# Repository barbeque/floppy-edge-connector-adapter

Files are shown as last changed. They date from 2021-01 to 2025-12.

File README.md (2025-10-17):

# Floppy Adapter v3
This adapter is intended to allow older computers equipped with 5.25" floppy drives using an edge connector to use a 3.5" floppy drive.

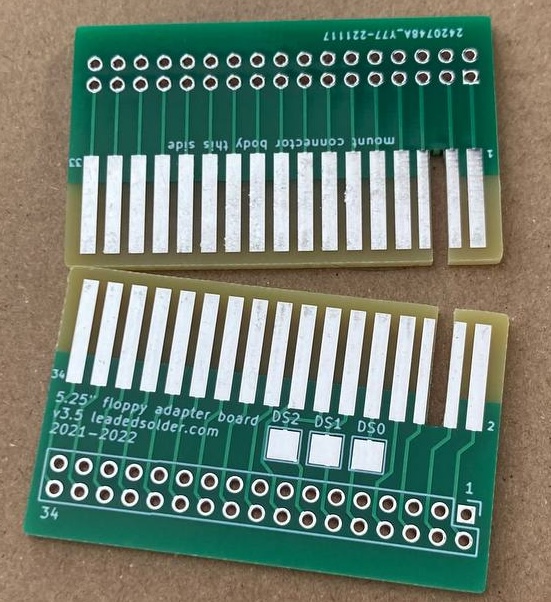
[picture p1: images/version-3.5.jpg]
The floppy adapter board (v3.5), with HASL coating and no bevel.


For long-term reliability, especially in humid environments or when the adapter is expected to be plugged and unplugged often, it's recommended that you pay extra at fabrication time to get hard gold fingers and a bevel. You can bevel it yourself with sandpaper, if needed.

This project was developed as part of a [leaded solder](https://www.leadedsolder.com/) repair of a Sharp X1turbo, and based on an older board developed for a conversion of a NEC PC-8801mkII.

# Version History
## v3.6 (2025)
Move the silkscreen for the female floppy-drive connector to match the label on the bottom of the board. The label was being ignored by assembly houses and this should help correct this behaviour.

## v3.5 (2022)
Add "drive select" breakout pins on the top. This was done to enable a single HxC to emulate two drives on the NEC PC-8801. Thanks to Frio for requesting and co-operating with the development of this version of the adapter.

## v3.0 (2021)
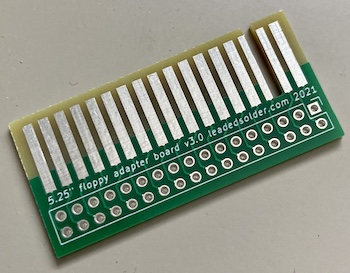
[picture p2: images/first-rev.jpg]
The floppy adapter board, with HASL coating and no bevel.


Original release of this board, fixing mounting issues from previous releases.

# Gerber files
You can get the gerber files from [the releases page](https://github.com/barbeque/floppy-edge-connector-adapter/releases/). My usual fabs are JLCPCB, PCBWay and Osh Park.

You can also [order it directly from the project page on PCBWay](https://www.pcbway.com/project/shareproject/5_25__Floppy_edge_connector_to_34_pin_3_5__floppy_drive_adapter.html), which gives me some PCBWay credit that I can use on future custom board projects.

# Bill of Materials
 * 34-pin female IDC right-angle header (0.100") such as [S9207-ND](https://www.digikey.ca/product-detail/en/sullins-connector-solutions/SFH11-PBPC-D17-RA-BK/S9207-ND/1990100) on DigiKey.

# Assembly instructions
 1. Solder the right-angle IDC connector to the board, such that the plastic part of the connector is on the side of the board reading "mount connector this side."
 2. Install adapter into your ribbon cable. If there is no key "tab" on your computer's connector, check for a red wire on the ribbon cable or a triangle marking on the ribbon cable connector in order to know which pin is "1."
 3. Attach drive to adapter, minding the tab on the right-angle IDC connector to get it the right way around.

# HxC Dual Drive support on PC-8801
Note: this only works on the "v3.5" adapter with drive select pads on the top of it.

A single HxC floppy emulator can emulate two floppy drives at once. This usually "just works," but on the PC-8801 you must wire it a special way using two adapters.

The PC-88 has two separate floppy cables instead of one "bussed" cable. Although most signals are bussed together to the floppy drive, each cable has its own independent drive select signal. Both of those selects are on drive select 0 (DS0) which means that we must put a partially-populated adapter into one of the drives in order to provide "its" DS0 to the HxC as drive select 1 (DS1.)

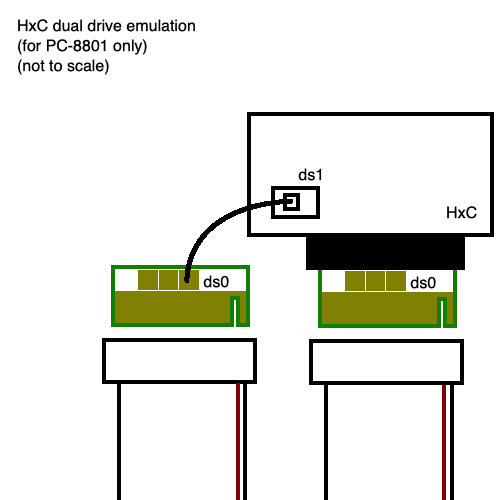
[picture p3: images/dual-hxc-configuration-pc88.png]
The dual drive emulation configuration for PC-8801


 1. Solder one adapter fully with a right-angle connector as per the previous instructions.
 2. Solder a DuPont jumper wire onto the "Drive Select 0" (DS0) pad of the second adapter.
 3. Install one adapter into each floppy cable on the PC-8801.
 4. Connect the fully-populated adapter to the HxC, and run the jumper wire from the other into the "DS1" select line on the back of the HxC.

For more guidance, please consult [the HxC forum thread for running two drives on a PC-8801.](https://torlus.com/floppy/forum/viewtopic.php?t=502)

# Tested on
 - NEC PC-8801mkII
 - NEC PC-8801mkIISR
 - Sanyo MBC-555
 - Sharp X1turbo
 - Sharp X1 Twin

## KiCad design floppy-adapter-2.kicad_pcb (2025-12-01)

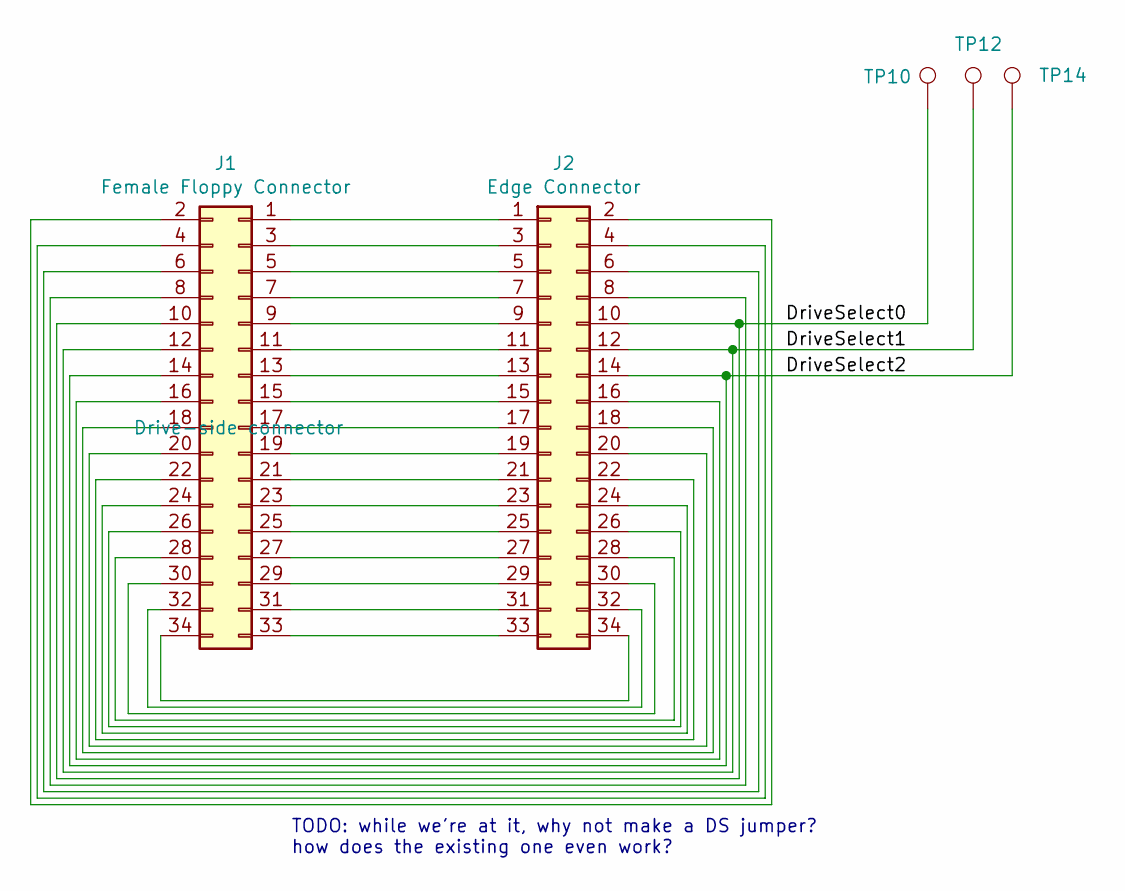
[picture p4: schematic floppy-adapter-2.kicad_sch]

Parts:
J1: Female Floppy Connector; Floppy_Connector
J2: Edge Connector; FloppyEdge
TP10, TP12, TP14: TestPoint; TestPoint_Pad_3.0x3.0mm

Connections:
/DriveSelect0: J1.10, J2.10, TP10.1
/DriveSelect1: J1.12, J2.12, TP12.1
/DriveSelect2: J1.14, J2.14, TP14.1
unnamed: J1.1, J2.1
unnamed: J1.2, J2.2
unnamed: J1.3, J2.3
unnamed: J1.4, J2.4
unnamed: J1.5, J2.5
unnamed: J1.6, J2.6
unnamed: J1.7, J2.7
unnamed: J1.8, J2.8
unnamed: J1.9, J2.9
unnamed: J1.11, J2.11
unnamed: J1.13, J2.13
unnamed: J1.15, J2.15
unnamed: J1.16, J2.16
unnamed: J1.17, J2.17
unnamed: J1.18, J2.18
unnamed: J1.19, J2.19
unnamed: J1.20, J2.20
unnamed: J1.21, J2.21
unnamed: J1.22, J2.22
unnamed: J1.23, J2.23
unnamed: J1.24, J2.24
unnamed: J1.25, J2.25
unnamed: J1.26, J2.26
unnamed: J1.27, J2.27
unnamed: J1.28, J2.28
unnamed: J1.29, J2.29
unnamed: J1.30, J2.30
unnamed: J1.31, J2.31
unnamed: J1.32, J2.32
unnamed: J1.33, J2.33
unnamed: J1.34, J2.34

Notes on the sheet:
TODO: while we're at it, why not make a DS jumper? how does the existing one even work?

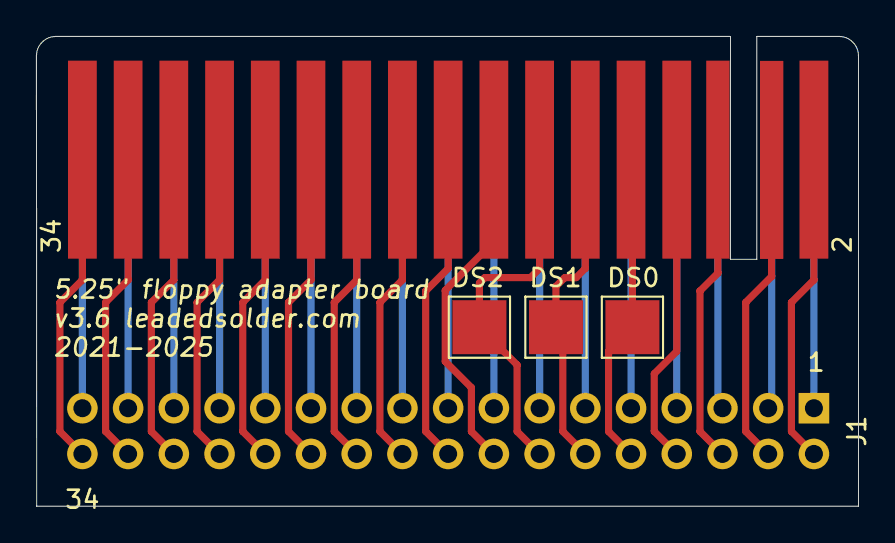
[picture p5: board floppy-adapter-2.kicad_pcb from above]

Board: 2 copper layers, 45.7 x 26.1 mm, 5 parts (1 on the bottom side), 34 nets.

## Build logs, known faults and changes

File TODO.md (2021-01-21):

- [x] Is the pin header around the right way so that the connector fits a Gotek properly? Should just be identical to the way the existing one is
- [x] Label which side of the board the connector goes to
- [x] Print out a sample board and compare to the real edge connector
- [x] Price at JLCPCB, fabs
- [x] Send off v3.0
- [ ] (v3.1) Figure out how to partially mask those pads

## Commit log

2021-01-21 Edges fit into a real X1
    [floppy-adapter-2.kicad_pcb, floppy-adapter-2.sch]
2021-01-21 footprint numbering
    [floppy-adapter-2.sch]
2021-01-21 Turn conn around properly
    [floppy-adapter-2.kicad_pcb]
2021-02-06 Fix my bonehead size mistake
    [floppy-adapter-2.kicad_pcb]
2021-02-09 README and BOM
2021-06-01 PCBWay link
2022-09-30 KiCad6; expose DS pins, lengthen board
    [floppy-adapter-2.kicad_pcb, floppy-adapter-2.kicad_sch, floppy-adapter-2.sch]
2023-07-31 KiCad 7
    [floppy-adapter-2.kicad_pcb, floppy-adapter-2.kicad_sch]
2025-10-17 Flip the silkscreen to the other side for the 34-pin connector, finally
    [floppy-adapter-2.kicad_pcb, floppy-adapter-2.kicad_sch]
2025-10-17 nice little chamfer
    [floppy-adapter-2.kicad_pcb]
2025-12-01 Make PCB shorter to avoid bottoming out against the female 34-pin
    [floppy-adapter-2.kicad_pcb]
